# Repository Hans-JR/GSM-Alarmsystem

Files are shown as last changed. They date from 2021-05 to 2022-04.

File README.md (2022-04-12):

# GSM-Alarmsystem
Based on Arduino Nano and SIM800L

The system provides 3 inputs. One is used for an PIR detector.
This PIR sends a HIGH-Signal of a certain time and returnes to low if no motion is detected.
If the signal is retrigered, a new message is being sent.
The other two inputs issue a message, if the input goes from low to high. Only one message is being sent per event.
The tel number and the individual text has to be entered into the script prior compilation.
If a terminal is connected to the Arduino serial port, all transmitted messages will be displayed on the terminal. The baudrate is 9600.
A PCB and a simple housing are available (folder KiCad and Gehäuse)

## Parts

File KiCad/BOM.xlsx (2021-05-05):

BOM for GSM Alarmsystem
 | Ref. Nr. | Bezeichnung | Artikel Nr. (Reichelt) | Link
 | C1 | 100nf | KERKO 100N | Keramik-Scheibenkondensatoren bei reichelt elektronik (https://www.reichelt.de/scheiben-c3169.html?ACTION=2&GROUPID=3169&START=0&OFFSET=16&nbc=1)
 | C2 | 470µf/16V | RAD 220/16 | Elektrolytkondensatoren, radiale Bauform und SMD-Elkos bei reichelt elektronik (https://www.reichelt.de/elkos-radial-85-c-c3143.html?ACTION=2&GROUPID=3143&START=0&OFFSET=16&nbc=1)
 | D1 | LED grün | LED 5MM GN | LED 5MM GN: LED, 5 mm, bedrahtet, grün, 18 mcd, 60° bei reichelt elektronik (https://www.reichelt.de/led-5-mm-bedrahtet-gruen-18-mcd-60--led-5mm-gn-p10232.html?search=led+5mm)
 | D2 | LED rot | LED 5MM RT | LED 5MM RT: LED, 5 mm, bedrahtet, rot, 4,5 mcd, 60° bei reichelt elektronik (https://www.reichelt.de/led-5-mm-bedrahtet-rot-4-5-mcd-60--led-5mm-rt-p10233.html?search=led+5mm)
 | F1 | Si 1,5A | PL 112000 | PL 112000: Sicherungshalter, Feinsicherungen 5x20mm, max. 6,3A - 250V bei reichelt elektronik (https://www.reichelt.de/sicherungshalter-feinsicherungen-5x20mm-max-6-3a-250v-pl-112000-p14678.html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)
 | J1 | Connector WAGO 250:250-202 | WAGO 250-202 | WAGO 250-202: Klemmleiste mit Betätigungsdrückern, RM 3,5 mm, 8A, 2-pol bei reichelt elektronik (https://www.reichelt.de/klemmleiste-mit-betaetigungsdrueckern-rm-3-5-mm-8a-2-pol-wago-250-202-p100833.html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)
 | J2 | Connector WAGO 250:250-202 | WAGO 250-202 | WAGO 250-202: Klemmleiste mit Betätigungsdrückern, RM 3,5 mm, 8A, 2-pol bei reichelt elektronik (https://www.reichelt.de/klemmleiste-mit-betaetigungsdrueckern-rm-3-5-mm-8a-2-pol-wago-250-202-p100833.html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)
 | J3 | Connector WAGO 250:250-203 | WAGO 250-203 | WAGO 250-203: Klemmleiste mit Betätigungsdrückern, RM 3,5 mm, 8A, 3-pol bei reichelt elektronik (https://www.reichelt.de/klemmleiste-mit-betaetigungsdrueckern-rm-3-5-mm-8a-3-pol-wago-250-203-p100834.html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)
 | J4 | Connector WAGO 250:250-204 | WAGO 250-204 | WAGO 250-204: Klemmleiste mit Betätigungsdrückern, RM 3,5 mm, 8A, 4-pol bei reichelt elektronik (https://www.reichelt.de/klemmleiste-mit-betaetigungsdrueckern-rm-3-5-mm-8a-4-pol-wago-250-204-p100835.html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)
 | R1 | 10k | VI MBB0207VD1002 | VI MBB0207VD1002: Dünnschichtwiderstand, axial, 0,11 W, 10 kOhm, 0,1% bei reichelt elektronik (https://www.reichelt.de/duennschichtwiderstand-axial-0-11-w-10-kohm-0-1--vi-mbb0207vd1002-p233785.html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)
 | R2 | 330 | VI MBA02040C3300 | VI MBA02040C3300: Dünnschichtwiderstand, axial, 0,4 W, 330 Ohm, 1% bei reichelt elektronik (https://www.reichelt.de/duennschichtwiderstand-axial-0-4-w-330-ohm-1--vi-mba02040c3300-p233643.html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)
 | R3 | 330 | VI MBA02040C3300 | VI MBA02040C3300: Dünnschichtwiderstand, axial, 0,4 W, 330 Ohm, 1% bei reichelt elektronik (https://www.reichelt.de/duennschichtwiderstand-axial-0-4-w-330-ohm-1--vi-mba02040c3300-p233643.html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)
 | U1 | LM2596S DC-DC Netzteil Adapter Step down Modul für Arduino | AZ-Delivery | LM2596S DC-DC Netzteil Adapter Step down Modul für Arduino – AZ-Delivery (https://www.az-delivery.de/collections/alle-produkte/products/lm2596s-dc-dc-step-down-modul-1)
 | U2 | SIM800L V2.0 Quad Band GSM GPRS Modul | Makershop | SIM800L V2.0 Quad Band GSM GPRS Modul Antenne Adapter Arduino Raspberry Pi | eBay (https://www.ebay.de/itm/253435858665?ssPageName=STRK%3AMEBIDX%3AIT&_trksid=p2060353.m2749.l2648)
 | U3 | Arduino Nano | AZ-Delivery | Nano V3.0 mit Atmega328 CH340! 100% Arduino kompatibel mit Nano V3 – AZ-Delivery (https://www.az-delivery.de/products/nano-v3-mit-ch340-arduino-kompatibel?_pos=1&_sid=d8a60455e&_ss=r)

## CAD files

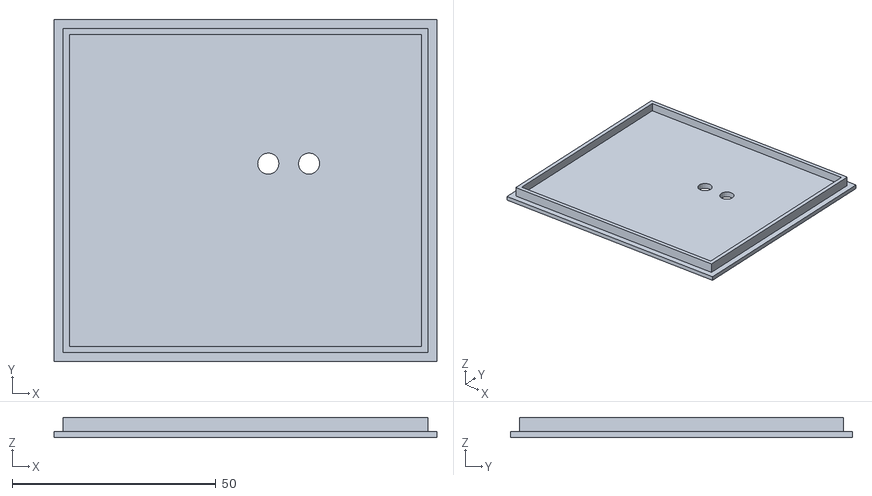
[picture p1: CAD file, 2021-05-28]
Gehäuse/Cover for GSM.stl
94.0 x 84.0 x 5.00

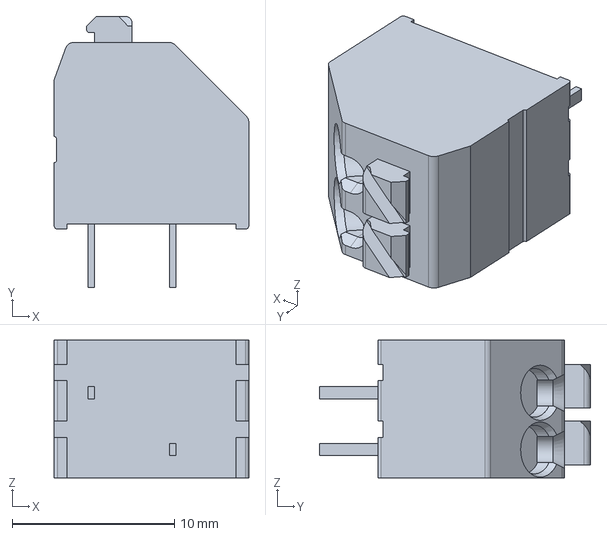
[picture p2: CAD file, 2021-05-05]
KiCad/Wago_250/3-D/250-202.stp
12.0 x 16.7 x 8.50 mm

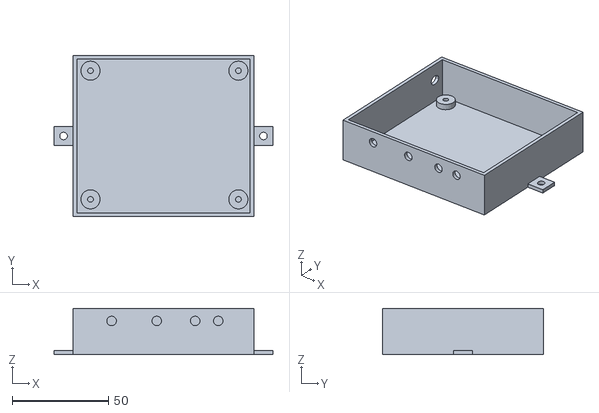
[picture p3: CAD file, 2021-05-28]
Gehäuse/Box for GSM.stl
114.0 x 84.0 x 24.0

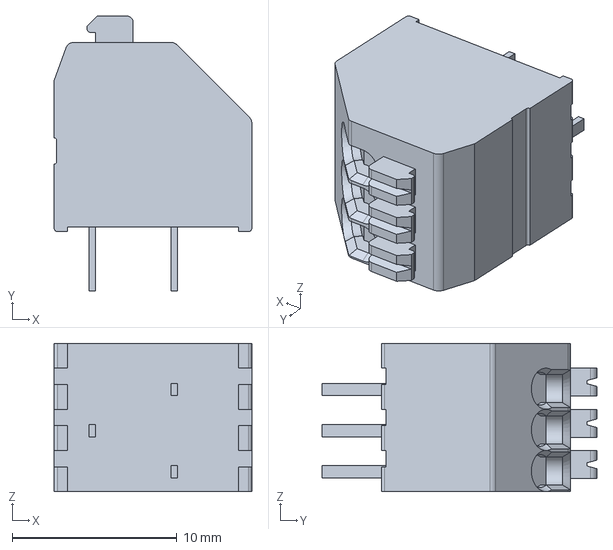
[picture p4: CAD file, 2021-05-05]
KiCad/Wago_250/3-D/250-403.stp
12.0 x 16.7 x 9.00 mm

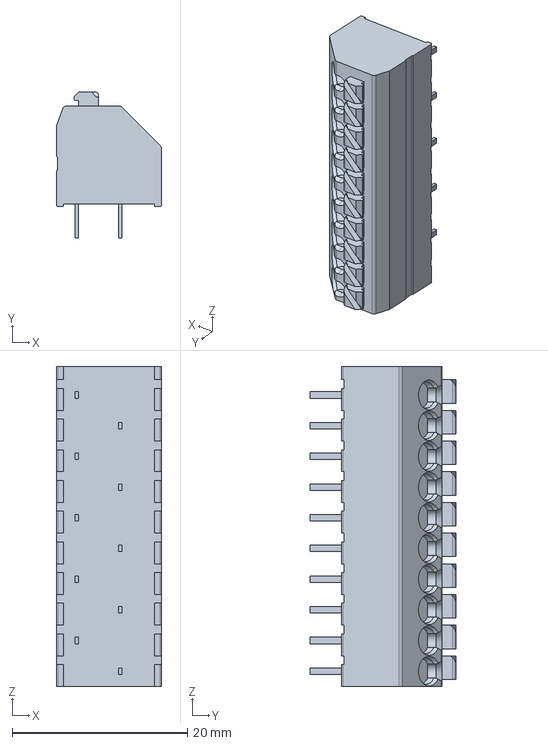
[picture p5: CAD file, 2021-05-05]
KiCad/Wago_250/3-D/250-210.stp
12.0 x 16.7 x 36.5 mm

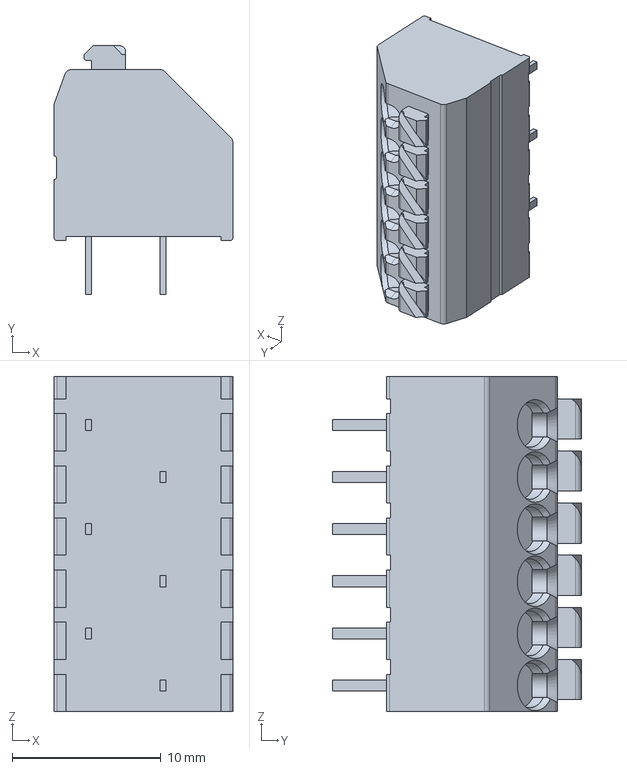
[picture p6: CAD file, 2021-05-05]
KiCad/Wago_250/3-D/250-206.stp
12.0 x 16.7 x 22.5 mm

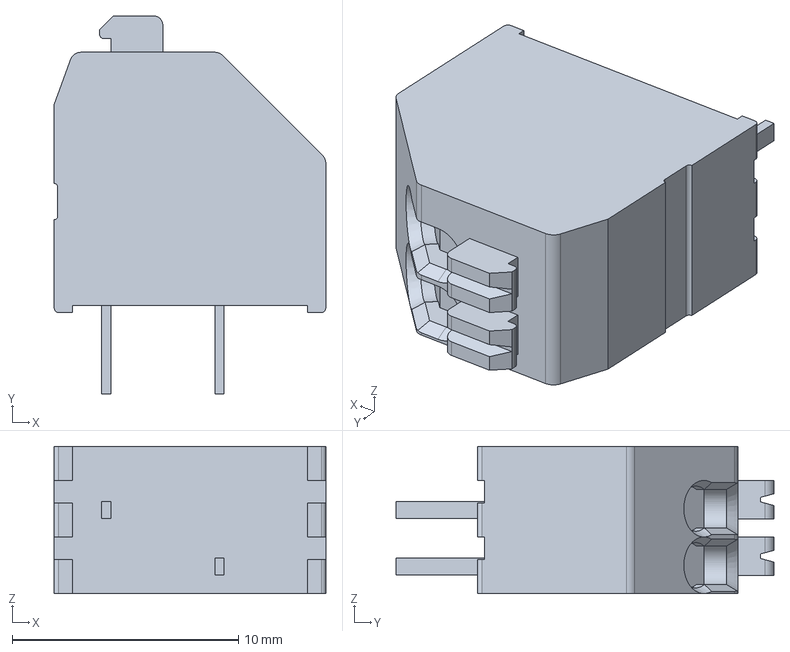
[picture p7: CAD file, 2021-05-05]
KiCad/Wago_250/3-D/250-402_000-004.stp
12.0 x 16.7 x 6.50 mm

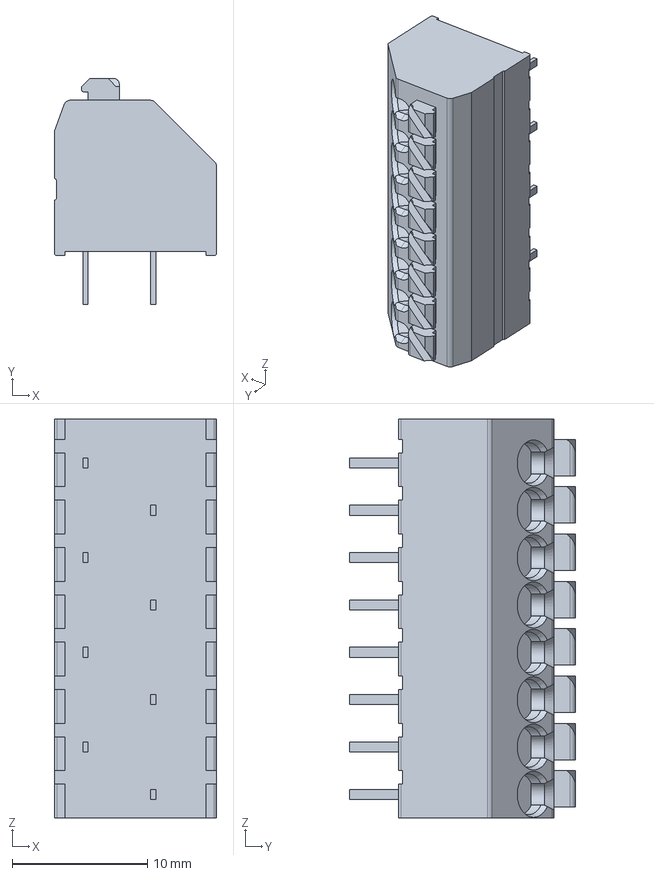
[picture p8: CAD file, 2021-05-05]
KiCad/Wago_250/3-D/250-208.stp
12.0 x 16.7 x 29.5 mm

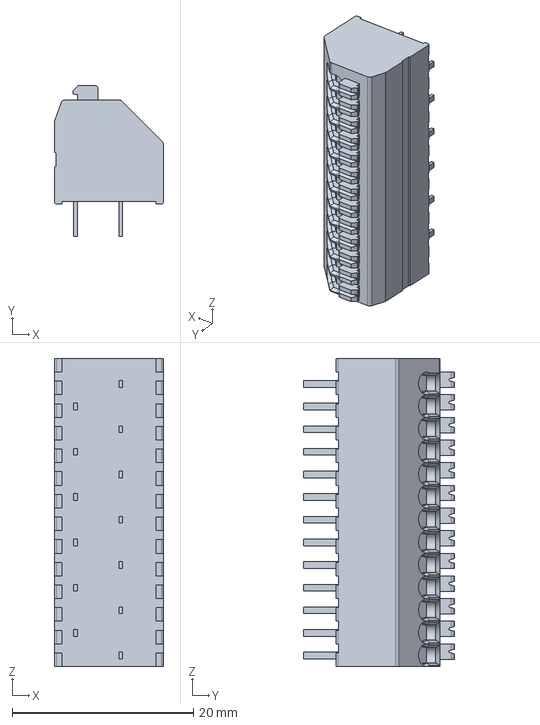
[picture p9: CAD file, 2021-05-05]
KiCad/Wago_250/3-D/250-413_000-006.stp
12.0 x 16.7 x 34.0 mm

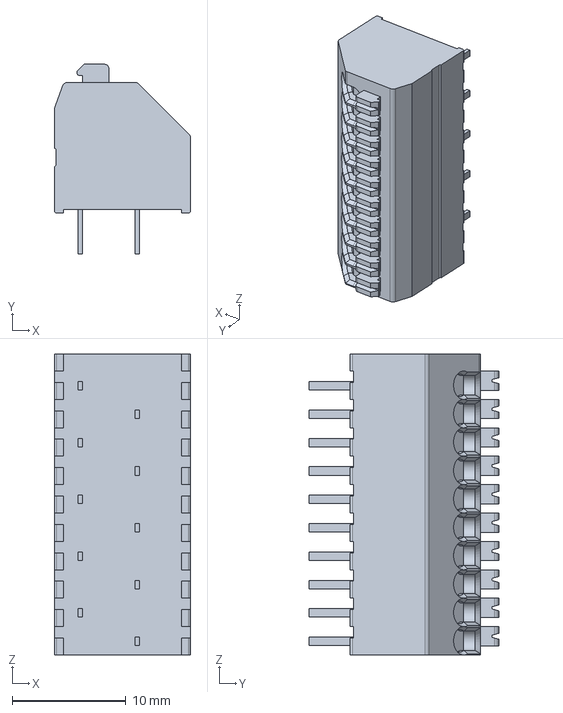
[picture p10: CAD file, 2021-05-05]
KiCad/Wago_250/3-D/250-410.stp
12.0 x 16.7 x 26.5 mm

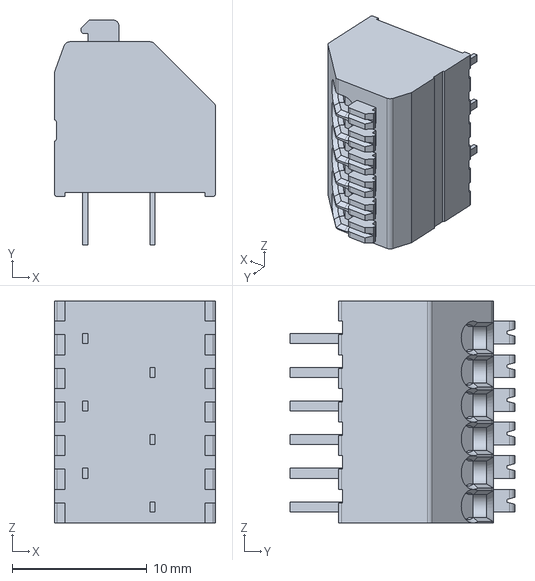
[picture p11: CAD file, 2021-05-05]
KiCad/Wago_250/3-D/250-406.stp
12.0 x 16.7 x 16.5 mm

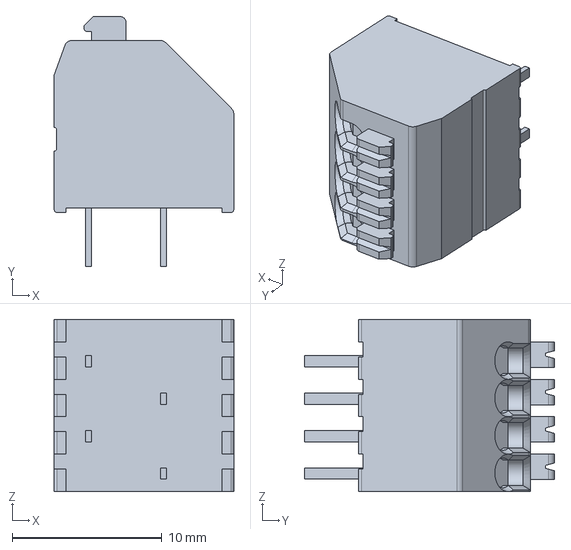
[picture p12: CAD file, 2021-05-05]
KiCad/Wago_250/3-D/250-404.stp
12.0 x 16.7 x 11.5 mm

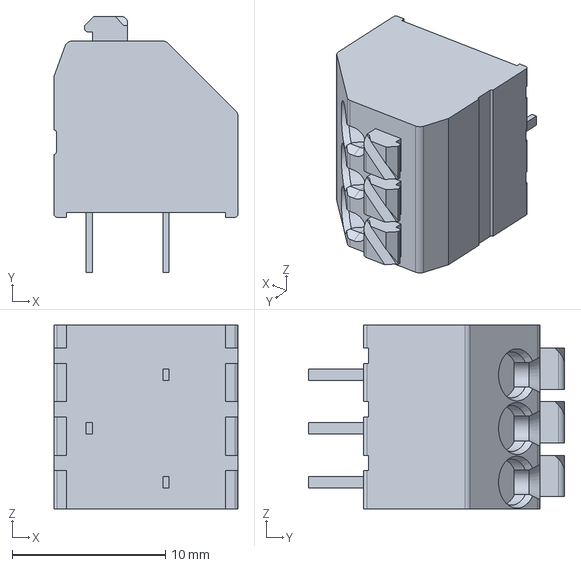
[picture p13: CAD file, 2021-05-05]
KiCad/Wago_250/3-D/250-203.stp
12.0 x 16.7 x 12.0 mm

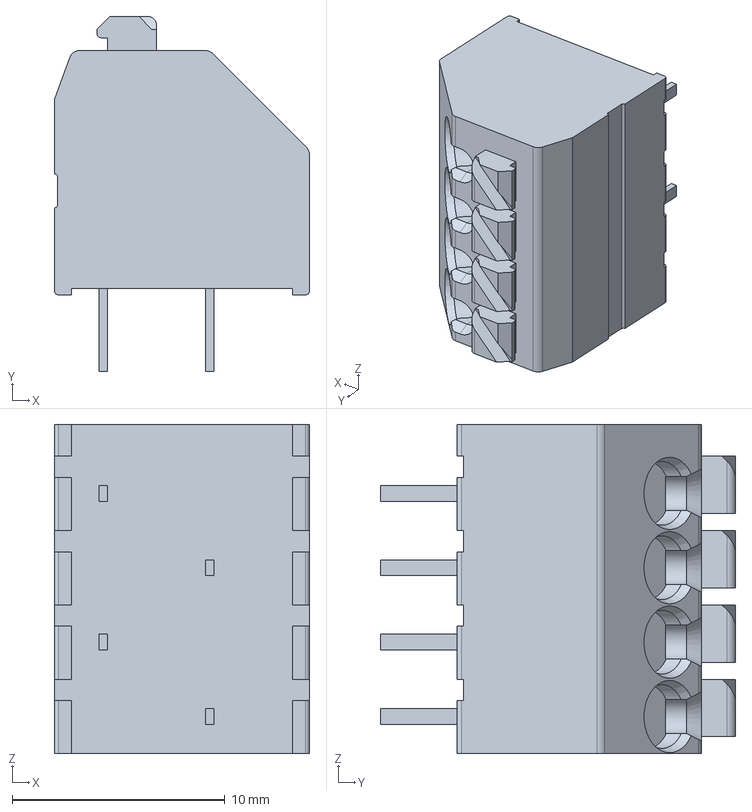
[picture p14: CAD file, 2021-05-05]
KiCad/Wago_250/3-D/250-204.stp
12.0 x 16.7 x 15.5 mm

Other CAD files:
KiCad/Wago_250/3-D/250-408.stp

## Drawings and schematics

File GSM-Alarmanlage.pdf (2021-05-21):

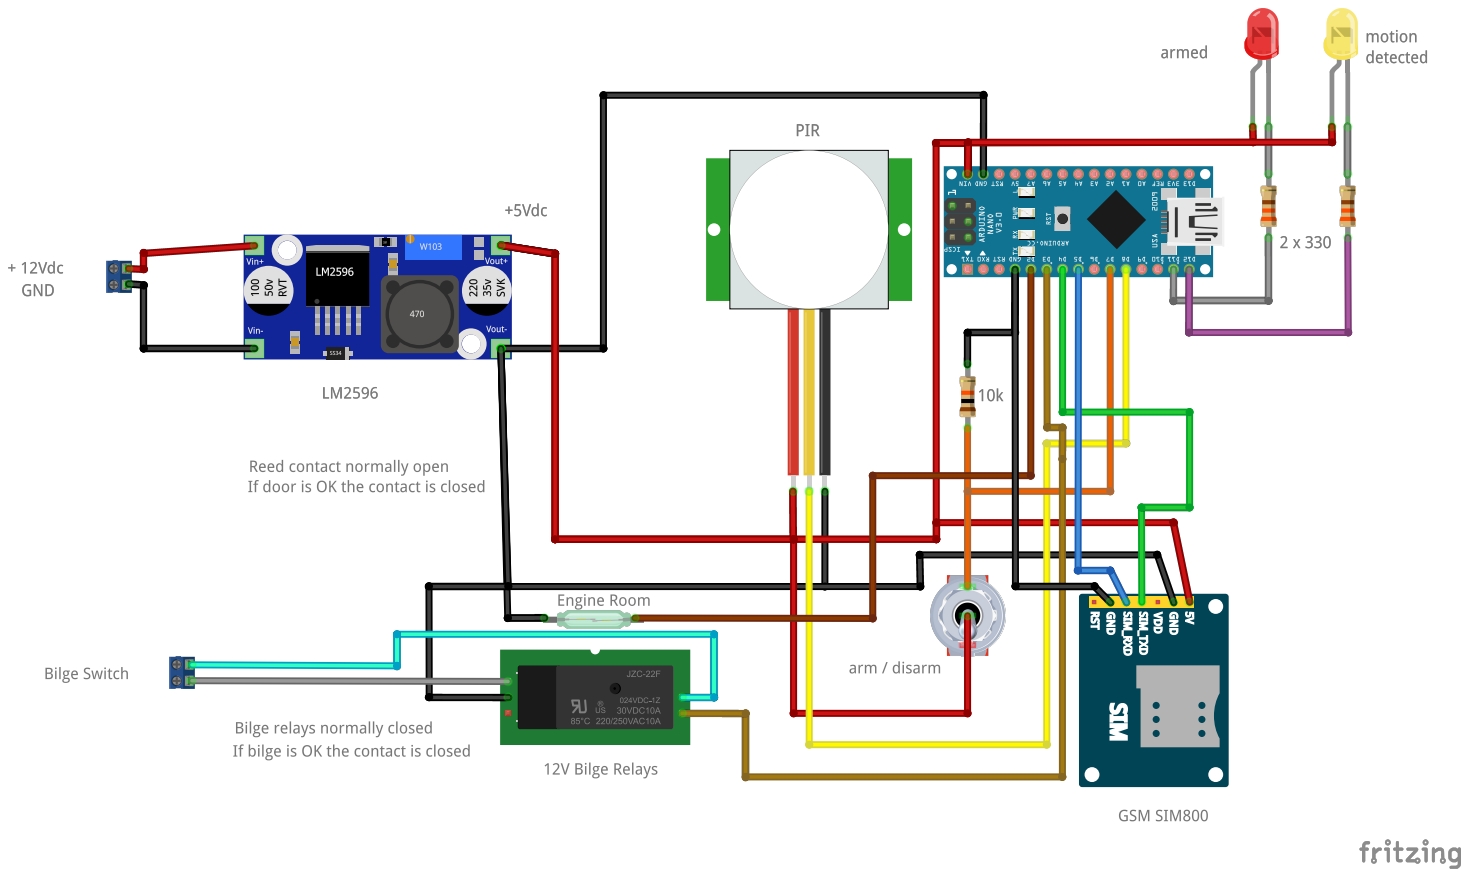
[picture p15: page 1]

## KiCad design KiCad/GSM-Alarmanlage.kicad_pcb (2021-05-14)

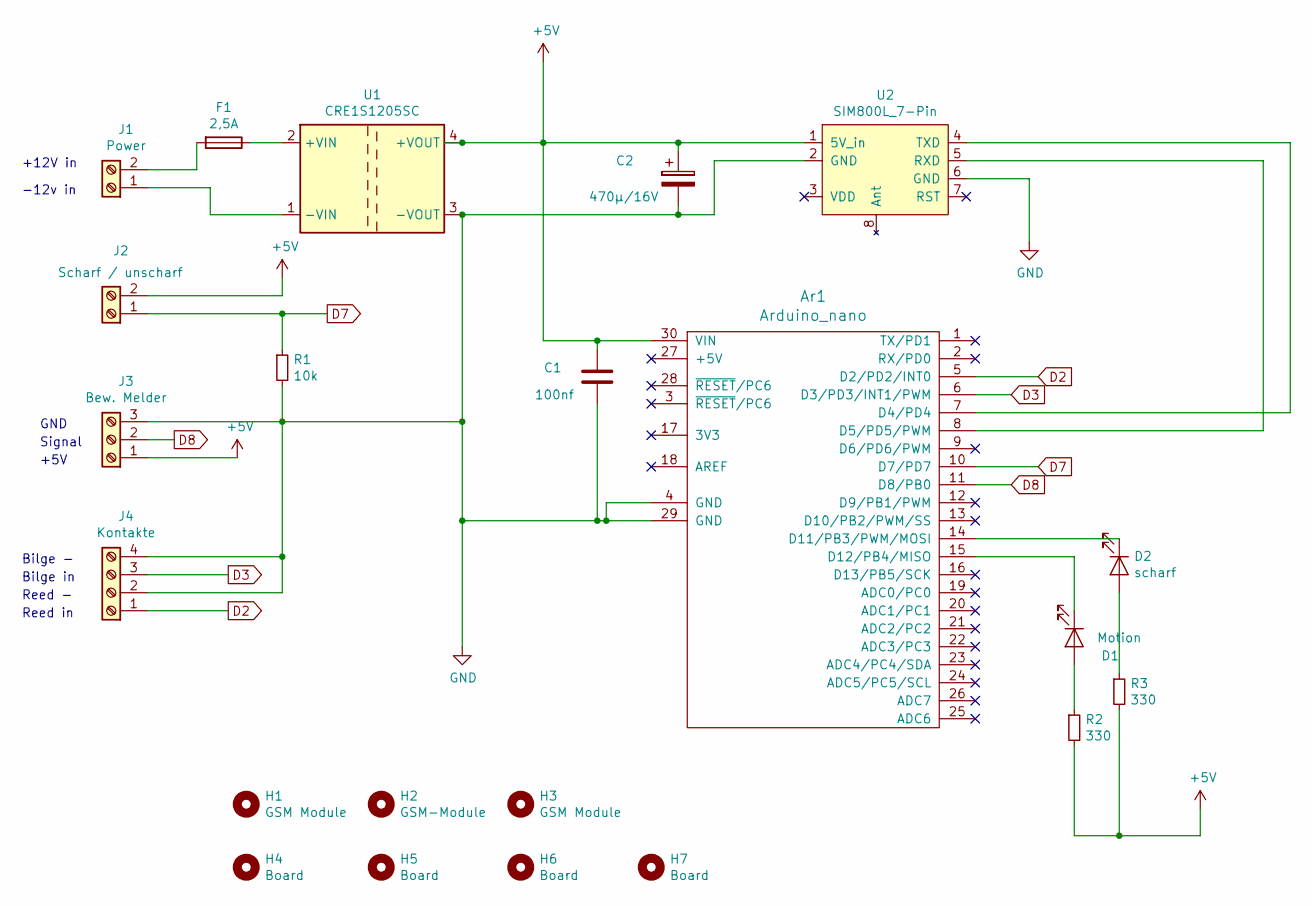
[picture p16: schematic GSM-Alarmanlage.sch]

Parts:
Ar1: Arduino_nano; ArduinoNano
C1: 100nf; C_Disc_D5.0mm_W2.5mm_P2.50mm
C2: 470µ/16V; CP_Radial_D8.0mm_P3.50mm
D1: Motion; LED_D5.0mm
D2: scharf; LED_D5.0mm
F1: 2,5A; Fuseholder_Cylinder-5x20mm_Stelvio-Kontek_PTF78_Horizontal_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
H1, H3: GSM Module; MountingHole_3.2mm_M3
H2: GSM-Module; MountingHole_3.2mm_M3
H4, H5, H6, H7: Board; MountingHole_3.2mm_M3
J1: Power; 250-202
J2: Scharf / unscharf; 250-202
J3: Bew. Melder; 250-203
J4: Kontakte; 250-204
R1: 10k; R_Axial_DIN0309_L9.0mm_D3.2mm_P12.70mm_Horizontal
R2, R3: 330; R_Axial_DIN0309_L9.0mm_D3.2mm_P12.70mm_Horizontal
U1: CRE1S1205SC; Converter_DCDC_LM2596S_Modul
U2: SIM800L_7-Pin

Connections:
+5V: Ar1.30 (VIN), C1.1, C2.1, J2.2, J3.1, R2.2, R3.2, U1.4 (+VOUT), U2.1 (5V_in)
D2: Ar1.5 (D2/PD2/INT0), J4.1
D3: Ar1.6 (D3/PD3/INT1/PWM), J4.3
D7: Ar1.10 (D7/PD7), J2.1, R1.1
D8: Ar1.11 (D8/PB0), J3.2
GND: Ar1.4 (GND), Ar1.29 (GND), C1.2, C2.2, J3.3, J4.2, J4.4, R1.2, U1.3 (-VOUT), U2.2 (GND), U2.6 (GND)
unnamed: Ar1.7 (D4/PD4), U2.4 (TXD)
unnamed: Ar1.8 (D5/PD5/PWM), U2.5 (RXD)
unnamed: Ar1.14 (D11/PB3/PWM/MOSI), D2.1 (K)
unnamed: Ar1.15 (D12/PB4/MISO), D1.1 (K)
unnamed: D1.2 (A), R2.1
unnamed: D2.2 (A), R3.1
unnamed: F1.1, U1.2 (+VIN)
unnamed: F1.2, J1.2
unnamed: J1.1, U1.1 (-VIN)

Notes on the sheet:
+12V in
-12v in
GND
Signal
+5V
Bilge -
Bilge in
Reed -
Reed in

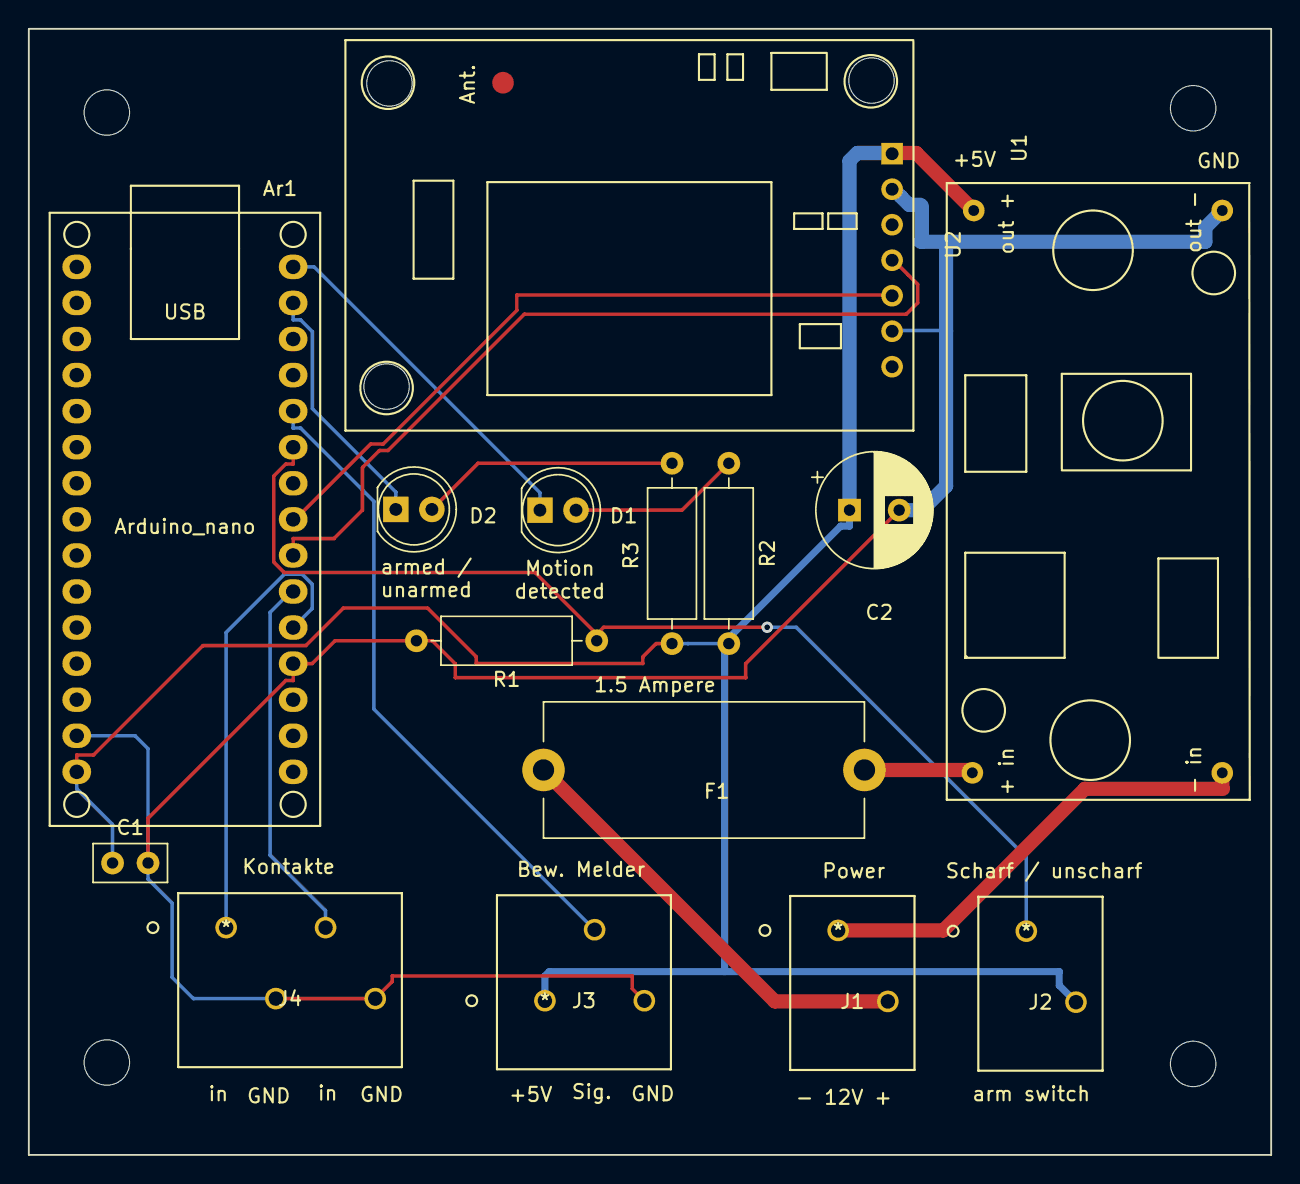
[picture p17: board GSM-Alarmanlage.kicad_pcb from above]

Board: 2 copper layers, 87.5 x 79.3 mm, 22 parts (0 on the bottom side), 15 nets.

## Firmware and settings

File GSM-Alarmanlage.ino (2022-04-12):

/*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

 It is based on  https://github.com/hub-stan/Arduino---alarm-control-panel-with-GSM
 
 Modified and compiled by Hans-J. Richter
 Version 1.0, May 1. 2021
 
The motion detector sends continously when output goes HIGH
The two other inputs detect a HIGH going signal. A message is being send each time when the signal goes from LOW to HIGH

Hardware: Aruino nano, GSM SIM800L
On Arduino nano only pins 2 and 3 can handle interrupts 

Connections: TxD > D4; RxD > D5; LED Motion > D12; LED armed > D11; PIR > D8; Contact 1 > D2, Contact 2 > D3

*/


#include <SoftwareSerial.h>

SoftwareSerial mySerial(4,5); //Rx and Tx to  SIM800  

char incomingByte;
String inputString;
int ledPin1 = 11;
int ledPin2 = 12;

bool active = false;
int button1 = 8 ;             // HIGH from Motion Detector
const byte InterruptPin2 = 2; // GND from Bilge Relays
const byte InterruptPin3 = 3; // GND Door Keller Reedswitch
int button4 = 7;              // 5v+ for arming the system (add a 10k resistor from pin to gnd)
bool button_State;            //Button state


void setup()
{
      pinMode (ledPin1, OUTPUT);
      pinMode (ledPin2, OUTPUT);
      pinMode(LED_BUILTIN, OUTPUT);
      Serial.begin(9600);
      mySerial.begin(9600);
      // Check if you're currently connected to mySerial
      while(!mySerial.available()){
        mySerial.println("AT");
        delay(1000);
        Serial.println("connecting....");
        }

      Serial.println("Connected.."); 
      mySerial.println("AT+CMGF=1\r\n");          //Set SMS Text Mode
      delay(1000); 
      mySerial.println("AT+CNMI=1,2,0,0,0");      //command to receive new messages from the network
      delay(1000);
      mySerial.println("AT+CMGL=\"REC UNREAD\""); // Read unread messages
      delay(1000);
      digitalWrite(LED_BUILTIN, HIGH);            // turn the LED on if modem is connected
      delay(1000); 

      pinMode(button1, INPUT);                                                  // Input from PIR-Sensor. High means motion detected
      pinMode(InterruptPin2, INPUT_PULLUP);                                     // from Bilge relays, if signal goes high alarm is initiated
      attachInterrupt(digitalPinToInterrupt(InterruptPin2), pin2_ISR, RISING);  // interrupt for Bilge relays
      pinMode(InterruptPin3, INPUT_PULLUP);                                     // from reed switch. If signal goes high alarm is initiated
      attachInterrupt(digitalPinToInterrupt(InterruptPin3), pin3_ISR, RISING);  // interrupt for reed contact
      pinMode(button4, INPUT);                                                  //The button is always LOW unless the switch is set to armed
      
        mySerial.begin(9600);                                                   //Module baude rate, this is on max, it depends on the version
        Serial.begin(9600);   
        delay(1000);                     
     }

void loop()
{ 
  digitalWrite(ledPin1, !digitalRead(7));   // Switches LED on if system is armed
  digitalWrite(ledPin2, !digitalRead(8));   // Switches LED on if motion is detected
  
  button_State = digitalRead(button1);      //We are constantly reading the button State

            if (button_State == HIGH && digitalRead(7) == true) { //Motion is detected & system armed
              Serial.println("Bew.Melder ausgelöst");             //Shows this message on the serial monitor
              delay(500);                                         //Small delay to avoid detecting the button press many times
  Serial.println("Sending SMS...");                               //Show this message on serial monitor
  mySerial.print("AT+CMGF=1\r");                                  //Set the module to SMS mode
  delay(100);
  mySerial.print("AT+CMGS=\"+49xxxxxxxxx\"\r"); //Your phone number don't forget to include your country code, example +212123456789"
  delay(500);
  mySerial.print("Bew.Melder ausgelöst");         //This is the text to send to the phone number, don't make it too long or you have to modify the SoftwareSerial buffer
  delay(500);
  mySerial.print((char)26);                       //End AT command with a ^Z, ASCII code 26
  delay(500);
  mySerial.println();
  Serial.println("Text Sent.");
  delay(500);
            }
            if (button_State == LOW)
            delay(100);
}
void pin2_ISR() {
            
      if (InterruptPin2 && digitalRead(7) == true) {    //Bilge switch is detected & system armed      
              Serial.println("Bilgenalarm");            //Shows this message on the serial monitor
              delay(200);                               //Small delay to avoid detecting the button press many times
  Serial.println("Sending SMS...");                     //Show this message on serial monitor
  mySerial.print("AT+CMGF=1\r");                        //Set the module to SMS mode
  delay(100);
  mySerial.print("AT+CMGS=\"+49xxxxxxxxx\"\r");      //Your phone number don't forget to include your country code, example +212123456789"
  delay(500);
  mySerial.print("Bilgenalarm");                        //This is the text to send to the phone number, don't make it too long or you have to modify the SoftwareSerial buffer
  delay(500);
  mySerial.print((char)26);                             //End AT command with a ^Z, ASCII code 26
  delay(500);
  mySerial.println();
  Serial.println("Text Sent.");
  delay(500);
            }
}

void pin3_ISR() {
         if (InterruptPin3 && digitalRead(7) == true) {   //Engineroom switch is detected & system armed
              Serial.println("Motorraum geöffnet");       //Shows this message on the serial monitor
              delay(200);                                 //Small delay to avoid detecting the button press many times
  Serial.println("Sending SMS...");                       //Show this message on serial monitor
  mySerial.print("AT+CMGF=1\r");                          //Set the module to SMS mode
  delay(100);
  mySerial.print("AT+CMGS=\"+49xxxxxxxxx\"\r");        //Your phone number don't forget to include your country code, example +212123456789"
  delay(500);
  mySerial.print("Motorraum geöffnet");                  //This is the text to send to the phone number, don't make it too long or you have to modify the SoftwareSerial buffer
  delay(500);
  mySerial.print((char)26);                               //End AT command with a ^Z, ASCII code 26
  delay(500);
  mySerial.println();
  Serial.println("Text Sent.");
  delay(500);
            }

      }

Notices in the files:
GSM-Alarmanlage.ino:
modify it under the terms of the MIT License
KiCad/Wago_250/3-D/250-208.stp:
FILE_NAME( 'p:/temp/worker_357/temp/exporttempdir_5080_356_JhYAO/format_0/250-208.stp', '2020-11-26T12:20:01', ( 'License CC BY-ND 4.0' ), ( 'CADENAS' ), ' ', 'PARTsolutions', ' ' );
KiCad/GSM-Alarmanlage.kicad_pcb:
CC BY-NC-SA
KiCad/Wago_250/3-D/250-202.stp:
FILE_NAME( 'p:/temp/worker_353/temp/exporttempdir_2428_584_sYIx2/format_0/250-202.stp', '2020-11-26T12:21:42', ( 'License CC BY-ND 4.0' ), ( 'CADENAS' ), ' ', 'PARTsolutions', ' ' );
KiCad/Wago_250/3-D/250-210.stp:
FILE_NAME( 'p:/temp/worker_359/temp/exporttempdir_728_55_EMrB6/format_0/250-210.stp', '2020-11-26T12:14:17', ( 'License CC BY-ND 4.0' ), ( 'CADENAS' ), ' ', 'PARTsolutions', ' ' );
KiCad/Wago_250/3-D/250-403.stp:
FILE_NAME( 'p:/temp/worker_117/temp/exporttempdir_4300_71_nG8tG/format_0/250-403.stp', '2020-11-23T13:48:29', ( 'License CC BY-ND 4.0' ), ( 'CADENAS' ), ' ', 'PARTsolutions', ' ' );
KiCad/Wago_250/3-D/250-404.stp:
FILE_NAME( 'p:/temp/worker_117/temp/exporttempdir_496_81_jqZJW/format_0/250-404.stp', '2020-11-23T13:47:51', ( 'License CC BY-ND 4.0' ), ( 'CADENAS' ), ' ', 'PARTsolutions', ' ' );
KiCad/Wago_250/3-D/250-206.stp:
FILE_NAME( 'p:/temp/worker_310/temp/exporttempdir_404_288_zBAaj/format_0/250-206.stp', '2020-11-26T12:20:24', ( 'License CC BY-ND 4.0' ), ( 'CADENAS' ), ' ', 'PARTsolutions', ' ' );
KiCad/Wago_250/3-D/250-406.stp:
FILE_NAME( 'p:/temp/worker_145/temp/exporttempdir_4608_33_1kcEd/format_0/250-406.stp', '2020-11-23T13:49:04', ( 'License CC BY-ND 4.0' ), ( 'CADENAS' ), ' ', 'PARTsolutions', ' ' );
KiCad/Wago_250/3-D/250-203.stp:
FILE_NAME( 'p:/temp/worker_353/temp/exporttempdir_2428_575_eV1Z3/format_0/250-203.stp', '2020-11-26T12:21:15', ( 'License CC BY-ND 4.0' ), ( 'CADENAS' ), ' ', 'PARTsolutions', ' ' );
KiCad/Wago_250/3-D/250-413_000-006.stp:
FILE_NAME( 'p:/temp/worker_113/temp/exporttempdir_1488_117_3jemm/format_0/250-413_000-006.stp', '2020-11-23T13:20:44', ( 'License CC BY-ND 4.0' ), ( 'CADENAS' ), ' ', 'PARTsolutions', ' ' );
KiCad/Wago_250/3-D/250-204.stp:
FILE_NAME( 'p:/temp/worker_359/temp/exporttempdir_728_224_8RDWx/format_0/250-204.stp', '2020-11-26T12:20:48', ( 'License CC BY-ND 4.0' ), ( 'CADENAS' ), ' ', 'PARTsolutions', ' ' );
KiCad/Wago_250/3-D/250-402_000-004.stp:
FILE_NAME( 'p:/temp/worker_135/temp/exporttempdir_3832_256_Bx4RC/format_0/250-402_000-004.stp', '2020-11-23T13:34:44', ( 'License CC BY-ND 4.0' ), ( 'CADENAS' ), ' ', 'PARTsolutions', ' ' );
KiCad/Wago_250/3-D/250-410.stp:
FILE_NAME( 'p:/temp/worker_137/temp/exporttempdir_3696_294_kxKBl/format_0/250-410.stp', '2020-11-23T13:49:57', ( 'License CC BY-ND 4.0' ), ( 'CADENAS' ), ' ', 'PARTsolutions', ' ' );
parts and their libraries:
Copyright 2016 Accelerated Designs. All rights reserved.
